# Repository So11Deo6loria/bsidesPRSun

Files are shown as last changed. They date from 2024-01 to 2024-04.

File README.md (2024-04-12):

badgePromo

# BSidesPR Taino Sun
Welcome to BSides Puerto Rico 2024!!! We were happy to have the opportunity to create this year's badge! 

# Functionality
The badge has a default color pattern but we made it highly configurable on purpose. We would love to see all the custom color schemes that people come up with! Come see us to learn more about how you can modify the badge! 

# Troubleshooting
Come find one of the makers on the back of the badge if you have any issues. We will be speaking in the Main Hall (104 B & C) from 1405-1435 on Friday and conducting workshops in 102B on Saturday from 1010-1125. 

Please note that if the badge is running consistently, the battery life will be limited.

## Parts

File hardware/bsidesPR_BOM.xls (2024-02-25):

PCBWay Bom Quotation, Product No.:T-Z9W584267A
Item # | *Designator | *Qty | Manufacturer | *Mfg Part # | Description / Value | *Package/Footprint | Mounting Type | Your Instructions / Notes | Unit Price | *Total | *Delivery Time | *Actual Purchase Mfg Part # | *PCBWay Note | Customer Reply | PCBWay Update
1 | BT1 | 1 |  | 2464 | Keystone 2464 | 2464 | Through Hole
2 | C1, C2, C4, C5 | 4 | Taiyo Yuden | JMK212BJ475MG-T | 4.7uF | Capacitor_SMD:C_0805_2012Metric_Pad1.18x1.45mm_HandSolder | Surface Mount, MLCC |  |  | $0.000
3 | C3 | 1 | Vishay Vitramon | VJ0603A3R3BXJCW1BC | 3.3pF | Capacitor_SMD:C_0603_1608Metric_Pad1.08x0.95mm_HandSolder | Surface Mount, MLCC |  |  | $0.000
4 | D1, D2, D3, D4, D5, D6, D7, D8, D9, D10, D11, D12, D13, D14, D15, D16, D17, D18, D19, D20, D21, D22, D23, D24, D25, D26, D27, D28, D29, D30, D31, D32, D33, D34, D35, D36, D37, D38, D39, D40, D41, D42, D43, D44, D45, D46, D47, D48, D49, D50 | 50 | worldsemi | SK6812 | WS2812B-B/W | LED_SMD:LED_WS2812B_PLCC4_5.0x5.0mm_P3.2mm |  |  |  | $0.000
5 | D51, D52 | 2 | onsemi |  | MBR0530T3G | Diode_SMD:D_SOD-123 | Surface Mount |  |  | $0.000
7 | J3 | 1 |  |  | Conn_01x03_Female | Connector_PinHeader_2.54mm:PinHeader_1x03_P2.54mm_Vertical |  | DNP: X
8 | L1 | 1 | TDK Corporation | MLP2520S3R3MT0S1 | 3.3uH | Inductor_SMD:L_1008_2520Metric_Pad1.43x2.20mm_HandSolder | Surface Mount |  |  | $0.000
9 | Q1 | 1 | Diodes Incorporated |  | 2N7002H | Package_TO_SOT_SMD:SOT-23 | Surface Mount |  |  | $0.000 |  | 2N7002H-7
10 | Q2 | 1 | Diodes Incorporated |  | DMP2012SN-7 | Package_TO_SOT_SMD:SOT-23 | Surface Mount
11 | R1, R4, R5 | 3 | YAGEO | RC0603FR-1310KL | 10k | Resistor_SMD:R_0603_1608Metric_Pad0.98x0.95mm_HandSolder | Surface Mount |  |  | $0.000
12 | R2 | 1 | YAGEO | RT0603FRE07620KL | 620k | Resistor_SMD:R_0603_1608Metric_Pad0.98x0.95mm_HandSolder | Surface Mount |  |  | $0.000
13 | R3 | 1 | YAGEO | RT0603FRE07200KL | 200k | Resistor_SMD:R_0603_1608Metric_Pad0.98x0.95mm_HandSolder | Surface Mount |  |  | $0.000
14 | R6 | 4 | YAGEO | RC0603FR-07499RL | 500 | Resistor_SMD:R_0603_1608Metric_Pad0.98x0.95mm_HandSolder | Surface Mount |  |  | $0.000
15 | SW1 | 1 | SHOU HAN | TS5225A | SW_MEC_5G | Button_Switch_SMD:SW_SPST_EVPBF | Surface Mount |  |  | $0.000
16 | U1 | 1 | raspberry pi | https://www.newark.com/raspberry-pi/raspberry-pi-pico/raspberry-pi-board-arm-cortex/dp/22AJ1097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 | Pico | MCU_RaspberryPi_and_Boards:RPi_Pico_SMD_TH | Surface Mount |  |  |  |  | 22AJ1097
17 | U2 | 1 | Texas Instruments | TPS61040DDCT | TPS61040DDC | Package_TO_SOT_SMD:SOT-23-5 | Surface Mount

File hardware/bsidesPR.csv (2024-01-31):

 |  |  |  |  |  |  | We have previously purchased a similar board and here are some details of that purchase.
# | Reference | Qty | Value | Footprint | Estimated Price (Per Board) | DNP | Actual Purchase Mfg Part # | Unit Price
1 | BT2 | 1 | 2477 | 2477:BAT_2477 | FALSE | X
2 | C1, C2, C4, C5 | 4 | 4.7uF | Capacitor_SMD:C_0805_2012Metric_Pad1.18x1.45mm_HandSolder | $0.384 |  | JMK212BJ475MG-T | $0.096
3 | C3 | 1 | 3.3pF | Capacitor_SMD:C_0603_1608Metric_Pad1.08x0.95mm_HandSolder | $0.104 |  | VJ0603A3R3BXJCW1BC | $0.104
4 | D1, D2, D3, D4, D5, D6, D7, D8, D9, D10, D11, D12, D13, D14, D15, D16, D17, D18, D19, D20, D21, D22, D23, D24, D25, D26, D27, D28, D29, D30, D31, D32, D33, D34, D35, D36, D37, D38, D39, D40, D41, D42, D43, D44, D45, D46, D47, D48, D49, D50 | 50 | WS2812B | LED_SMD:LED_WS2812B_PLCC4_5.0x5.0mm_P3.2mm | $2.250 |  | SK6812 | $0.045
5 | D51, D52 | 2 | BAT54W-HG3-18 | Diode_SMD:D_SOD-123 | $0.326 |  |  | $0.163
6 | J1 | 1 | Conn_02x03_Odd_Even | Connector_PinHeader_2.54mm:PinHeader_2x03_P2.54mm_Vertical | FALSE | X
7 | J3 | 1 | Conn_01x03_Female | Connector_PinHeader_2.54mm:PinHeader_1x03_P2.54mm_Vertical | FALSE | X
8 | L1 | 1 | 3.3uH | Inductor_SMD:L_1008_2520Metric_Pad1.43x2.20mm_HandSolder | $0.089 |  | MLP2520S3R3MT0S1 | $0.089
9 | Q1 | 1 | 2N7002H | Package_TO_SOT_SMD:SOT-23 | $0.299 |  |  | $0.299
10 | Q2 | 1 | DMP2012SN-7 | Package_TO_SOT_SMD:SOT-23 | $0.158 |  |  | $0.158
11 | R1, R4, R5 | 3 | 10k | Resistor_SMD:R_0603_1608Metric_Pad0.98x0.95mm_HandSolder | $0.003 |  | RC0603FR-1310KL | $0.001
12 | R2 | 1 | 620k | Resistor_SMD:R_0603_1608Metric_Pad0.98x0.95mm_HandSolder | $0.016 |  | RT0603FRE07620KL | $0.016
13 | R3 | 1 | 200k | Resistor_SMD:R_0603_1608Metric_Pad0.98x0.95mm_HandSolder | $0.015 |  | RT0603FRE07200KL | $0.015
14 | R6, R7, R8, R9 | 4 | 500 | Resistor_SMD:R_0603_1608Metric_Pad0.98x0.95mm_HandSolder | $0.008 |  | RC0603FR-07499RL | $0.002
15 | SW1 | 1 | SW_MEC_5G | Button_Switch_SMD:SW_SPST_EVPBF | $0.027 |  | TS5225A | $0.027
16 | U1 | 1 | Pico | MCU_RaspberryPi_and_Boards:RPi_Pico_SMD_TH | $5.000 |  | https://www.newark.com/raspberry-pi/raspberry-pi-pico/raspberry-pi-board-arm-cortex/dp/22AJ1097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 | $5.000
17 | U2 | 1 | TPS61040DDC | Package_TO_SOT_SMD:SOT-23-5 | $0.494 |  | TPS61040DDCT | $0.494
 |  |  |  | Estimated BoM | $9.173
 |  |  |  | Total Boards | 300
 |  |  |  | Estimated Material Cost | $2,751.90

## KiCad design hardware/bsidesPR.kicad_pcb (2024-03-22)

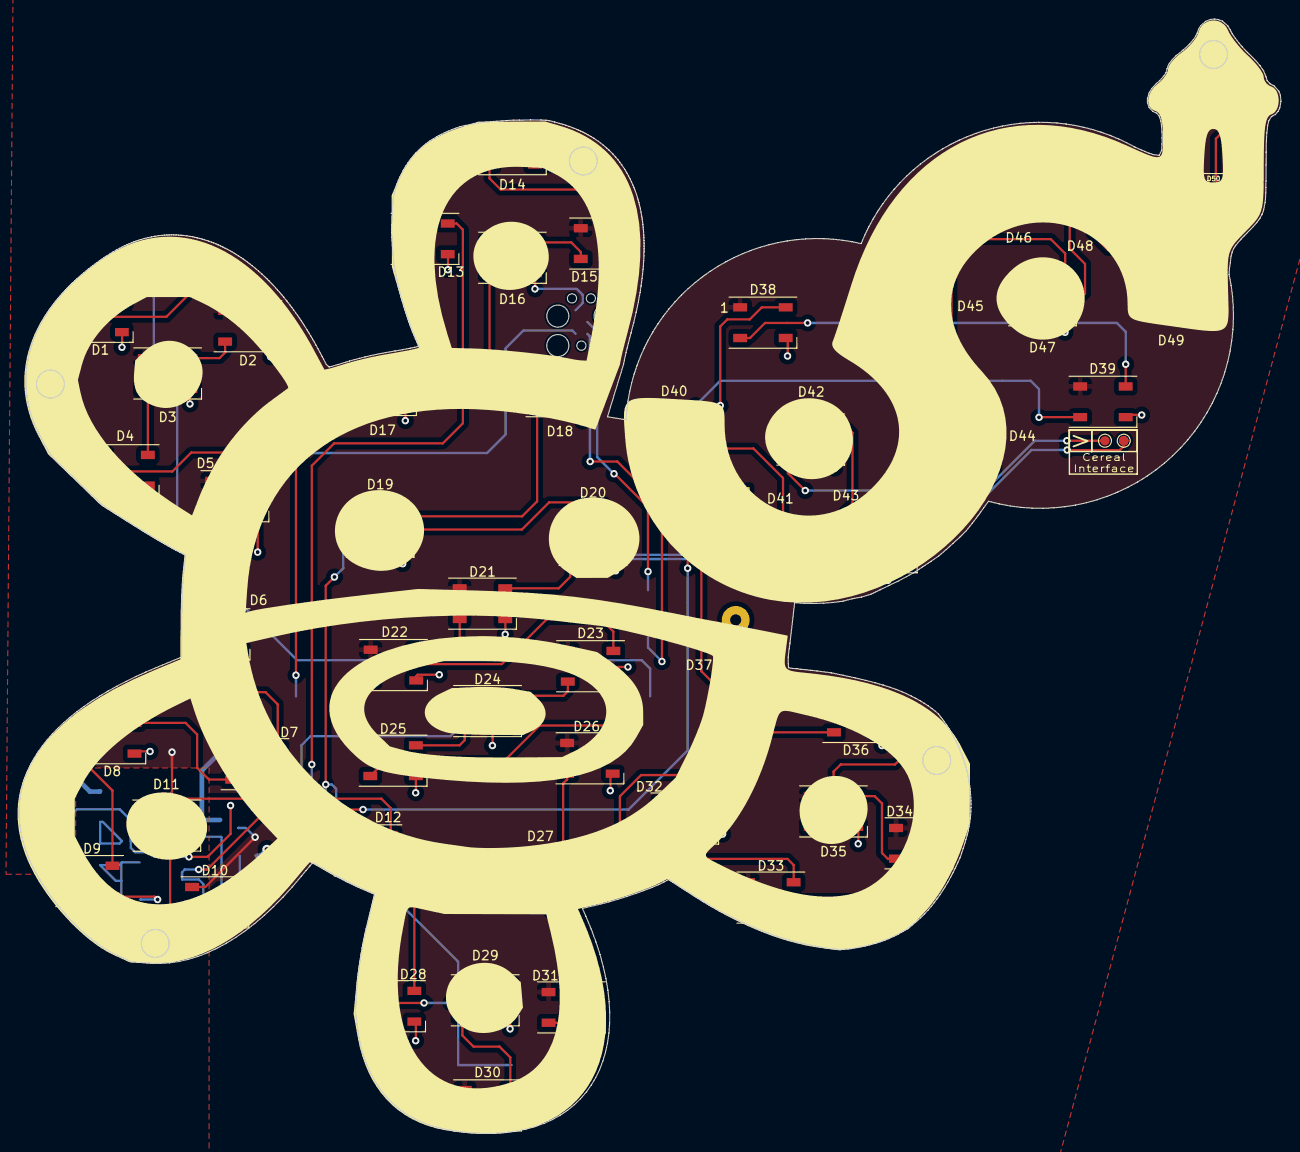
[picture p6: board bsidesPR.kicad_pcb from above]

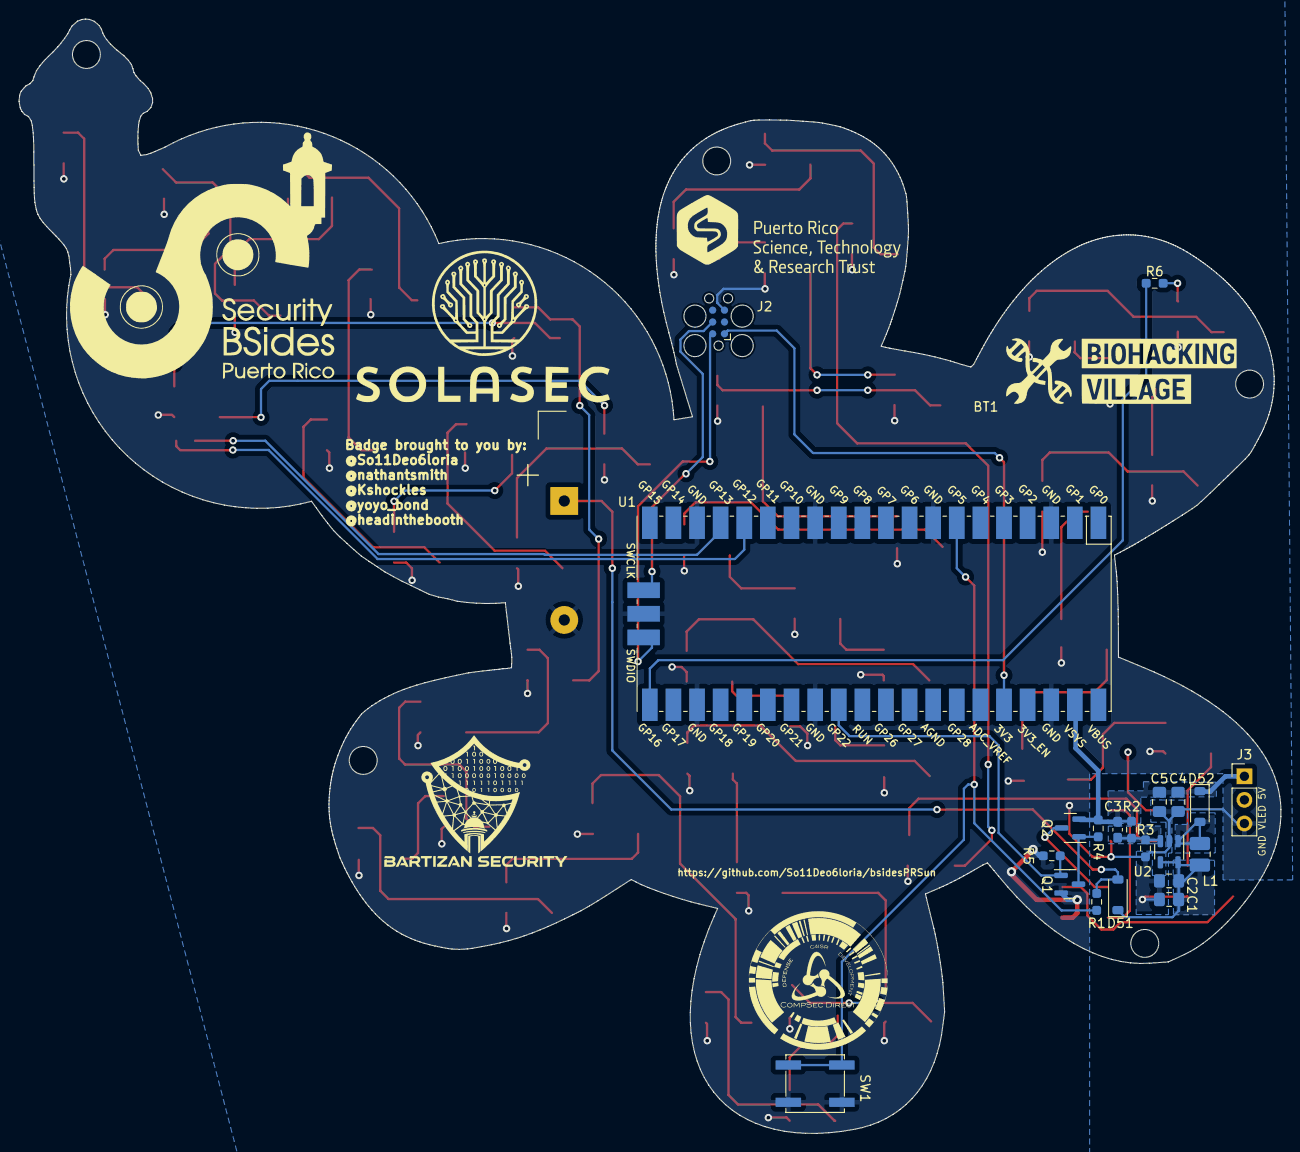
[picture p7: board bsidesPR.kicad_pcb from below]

Board: 2 copper layers, 135.8 x 119.9 mm, 72 parts (22 on the bottom side), 64 nets.

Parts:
BT1: Battery; BatteryHolder_TruPower_BH-331P_3xAA
C1, C2, C4, C5: 4.7uF; C_0805_2012Metric_Pad1.18x1.45mm_HandSolder
C3: 3.3pF; C_0603_1608Metric_Pad1.08x0.95mm_HandSolder
D1, D2, D3, D4, D5, D6, D7, D8, D9, D10, D11, D12, D13, D14, D15, D16, D17, D18, D19, D20, D21, D22, D23, D24, D25, D26, D27, D28, D29, D30, D31, D32, D33, D34, D35, D36, D37, D38, D39, D40, D41, D42, D43, D44, D45, D46, D47, D48, D49, D50: WS2812B; LED_WS2812B_PLCC4_5.0x5.0mm_P3.2mm
D51, D52: BAT54W-HG3-18; D_SOD-123
J2: Conn_ARM_SWD_TagConnect_TC2030; Tag-Connect_TC2030-IDC-FP_2x03_P1.27mm_Vertical
J3: Conn_01x03_Female; PinHeader_1x03_P2.54mm_Vertical
L1: 3.3uH; L_1008_2520Metric_Pad1.43x2.20mm_HandSolder
Q1: 2N7002H; SOT-23
Q2: DMP2012SN-7; SOT-23
R1, R4, R5: 10k; R_0603_1608Metric_Pad0.98x0.95mm_HandSolder
R2: 620k; R_0603_1608Metric_Pad0.98x0.95mm_HandSolder
R3: 200k; R_0603_1608Metric_Pad0.98x0.95mm_HandSolder
R6: 500; R_0603_1608Metric_Pad0.98x0.95mm_HandSolder
SW1: SW_MEC_5G; SW_SPST_EVPBF
U1: Pico; RPi_Pico_SMD_TH
U2: TPS61040DDC; SOT-23-5

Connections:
+3V3: J2.1 (VCC), U1.36 (3V3)
+5V: C3.1, C4.1, C5.1, D52.1 (K), J3.1, Q2.2 (S), R2.1, R4.1, U1.39 (VSYS)
/EN: C1.1, C2.1, D51.1 (K), L1.1, U2.4 (EN), U2.5 (VIN)
/FB: C3.2, R2.2, R3.1, U2.3 (FB)
/SW: D52.2 (A), L1.2, U2.1 (SW)
ENABLE_VLED: Q1.1 (G), R5.1, U1.29 (GPIO22)
GND: BT1.2 (-), C1.2, C2.2, C4.2, C5.2, D1.3 (VSS), D2.3 (VSS), D3.3 (VSS), D4.3 (VSS), D5.3 (VSS), D6.3 (VSS), D7.3 (VSS), D8.3 (VSS), D9.3 (VSS), D10.3 (VSS), D11.3 (VSS), D12.3 (VSS), D13.3 (VSS), D14.3 (VSS), D15.3 (VSS), D16.3 (VSS), D17.3 (VSS), D18.3 (VSS), D19.3 (VSS), D20.3 (VSS), D21.3 (VSS), D22.3 (VSS), D23.3 (VSS), D24.3 (VSS), D25.3 (VSS), D26.3 (VSS), D27.3 (VSS), D28.3 (VSS), D29.3 (VSS), D30.3 (VSS), D31.3 (VSS), D32.3 (VSS), D33.3 (VSS), D34.3 (VSS), D35.3 (VSS), D36.3 (VSS), D37.3 (VSS), D38.3 (VSS), D39.3 (VSS), D40.3 (VSS), D41.3 (VSS), D42.3 (VSS), D43.3 (VSS), D44.3 (VSS), D45.3 (VSS), D46.3 (VSS), D47.3 (VSS), D48.3 (VSS), D49.3 (VSS), D50.3 (VSS), J2.5 (GND), J3.3, Q1.2 (S), R3.2, R5.2, SW1.2 (B), SW1.4 (B), U1.3 (GND), U1.8 (GND), U1.13 (GND), U1.18 (GND), U1.23 (GND), U1.28 (GND), U1.38 (GND), U1.42 (GND), U2.2 (GND)
LED_PIN: R6.1, U1.21 (GPIO16)
unnamed: BT1.1 (+), D51.2 (A), R1.1
unnamed: D1.4 (DIN), R6.2
unnamed: D1.2 (DOUT), D2.4 (DIN)
unnamed: D2.2 (DOUT), D3.4 (DIN)
unnamed: D3.2 (DOUT), D4.4 (DIN)
unnamed: D4.2 (DOUT), D5.4 (DIN)
unnamed: D5.2 (DOUT), D6.4 (DIN)
unnamed: D6.2 (DOUT), D7.4 (DIN)
unnamed: D7.2 (DOUT), D8.4 (DIN)
unnamed: D8.2 (DOUT), D9.4 (DIN)
unnamed: D9.2 (DOUT), D10.4 (DIN)
unnamed: D10.2 (DOUT), D11.4 (DIN)
unnamed: D11.2 (DOUT), D12.4 (DIN)
unnamed: D12.2 (DOUT), D13.4 (DIN)
unnamed: D13.2 (DOUT), D14.4 (DIN)
unnamed: D14.2 (DOUT), D15.4 (DIN)
unnamed: D15.2 (DOUT), D16.4 (DIN)
unnamed: D16.2 (DOUT), D17.4 (DIN)
unnamed: D17.2 (DOUT), D18.4 (DIN)
unnamed: D18.2 (DOUT), D19.4 (DIN)
unnamed: D19.2 (DOUT), D20.4 (DIN)
unnamed: D20.2 (DOUT), D21.4 (DIN)
unnamed: D21.2 (DOUT), D22.4 (DIN)
unnamed: D22.2 (DOUT), D23.4 (DIN)
unnamed: D23.2 (DOUT), D24.4 (DIN)
unnamed: D24.2 (DOUT), D25.4 (DIN)
unnamed: D25.2 (DOUT), D26.4 (DIN)
unnamed: D26.2 (DOUT), D27.4 (DIN)
unnamed: D27.2 (DOUT), D28.4 (DIN)
unnamed: D28.2 (DOUT), D29.4 (DIN)
unnamed: D29.2 (DOUT), D30.4 (DIN)
unnamed: D30.2 (DOUT), D31.4 (DIN)
unnamed: D31.2 (DOUT), D32.4 (DIN)
unnamed: D32.2 (DOUT), D33.4 (DIN)
unnamed: D33.2 (DOUT), D34.4 (DIN)
unnamed: D34.2 (DOUT), D35.4 (DIN)
unnamed: D35.2 (DOUT), D36.4 (DIN)
unnamed: D36.2 (DOUT), D37.4 (DIN)
unnamed: D37.2 (DOUT), D38.4 (DIN)
unnamed: D38.2 (DOUT), D39.4 (DIN)
unnamed: D39.2 (DOUT), D40.4 (DIN)
unnamed: D40.2 (DOUT), D41.4 (DIN)
unnamed: D41.2 (DOUT), D42.4 (DIN)
unnamed: D42.2 (DOUT), D43.4 (DIN)
unnamed: D43.2 (DOUT), D44.4 (DIN)
unnamed: D44.2 (DOUT), D45.4 (DIN)
unnamed: D45.2 (DOUT), D46.4 (DIN)
unnamed: D46.2 (DOUT), D47.4 (DIN)
unnamed: D47.2 (DOUT), D48.4 (DIN)
unnamed: D48.2 (DOUT), D49.4 (DIN)
unnamed: D49.2 (DOUT), D50.4 (DIN)
unnamed: J2.4 (SWCLK), U1.41 (SWCLK)
unnamed: J2.2 (SWDIO), U1.43 (SWDIO)
unnamed: Q1.3 (D), Q2.1 (G), R4.2
RPi_WAKE: R1.2, SW1.1 (A), U1.7 (GPIO5)
VLED: D1.1 (VDD), D2.1 (VDD), D3.1 (VDD), D4.1 (VDD), D5.1 (VDD), D6.1 (VDD), D7.1 (VDD), D8.1 (VDD), D9.1 (VDD), D10.1 (VDD), D11.1 (VDD), D12.1 (VDD), D13.1 (VDD), D14.1 (VDD), D15.1 (VDD), D16.1 (VDD), D17.1 (VDD), D18.1 (VDD), D19.1 (VDD), D20.1 (VDD), D21.1 (VDD), D22.1 (VDD), D23.1 (VDD), D24.1 (VDD), D25.1 (VDD), D26.1 (VDD), D27.1 (VDD), D28.1 (VDD), D29.1 (VDD), D30.1 (VDD), D31.1 (VDD), D32.1 (VDD), D33.1 (VDD), D34.1 (VDD), D35.1 (VDD), D36.1 (VDD), D37.1 (VDD), D38.1 (VDD), D39.1 (VDD), D40.1 (VDD), D41.1 (VDD), D42.1 (VDD), D43.1 (VDD), D44.1 (VDD), D45.1 (VDD), D46.1 (VDD), D47.1 (VDD), D48.1 (VDD), D49.1 (VDD), D50.1 (VDD), J3.2, Q2.3 (D)

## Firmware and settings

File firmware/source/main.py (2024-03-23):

import lowpower
import utime
import time # Remove later
import machine
import _thread
import constants
import prettyLights
import cerealInterface
import ujson
from machine import Pin, Timer

class Main:
    def __init__(self):
        print("Start Up") # only print after receiving signal on Pin number DORMANT_PIN
        self.runLoop()

    def lowPowerPause(self):
        self.leds.shutdown()
        while(self.button.value() != 1):
            utime.sleep_ms(10)
        lowpower.dormant_until_pin(constants.BUTTON)
        self.leds.wakeup()

    def read_config(self):
        try:
            with open('config.json', 'r') as f:
                data = ujson.load(f)
                return data
        except:
            return False
        
    def runLoop(self):
        config = self.read_config()
        if(config):
            print("Loading following configuration:")
            print(config)
            self.startupColorName = config['startupColor']
            self.flagName = config['flag']
            self.sleepTimeout = config['sleepTimeout']
        else:
            print("Loading default configuration")
            self.startupColorName = 'white',
            self.flagName = 'puertoRicoFlag'
            self.sleepTimeout = 300 # 300 seconds
        self.button = Pin(constants.BUTTON, Pin.IN, Pin.PULL_UP)

        #Initialize LED Manager and Turn on Power
        self.leds = prettyLights.LEDS(self.flagName, self.startupColorName)
        self.leds.wakeup()
        self.leds.startupAnimation()

        serialInterface = cerealInterface.CerealInterface(self.leds)
        _thread.start_new_thread(serialInterface.uartShell, ())        

        #Capture the Bootup Time
        startTime = utime.ticks_ms()

        while(True):
            if((self.button.value() != 1) or (utime.ticks_diff(utime.ticks_ms(), startTime) > self.sleepTimeout*1000)):
                print("getting sleepy")
                self.lowPowerPause()
                startTime = utime.ticks_ms()
                self.leds.startupAnimation()
            self.leds.waveDaFlag()
            time.sleep(0.025)

Main()

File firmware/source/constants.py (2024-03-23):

# Board Configuration
BUTTON = 5
PICO_LED_PIN = 25

# LED Constants
LED_OFF = tuple([0, 0, 0])
LED_MAX = 0.200
WAVE_DELAY = 0.1
LED_COUNT = 50

# Serial/UART constants
CEREAL_TX_PIN = 12  # GPIO 12 Pin 16
CEREAL_RX_PIN = 13  # GPIO 13 Pin 17
BAUD_RATE = 115200

COLOR_MAPPING = {
    "white": [255, 255, 255],
    "red": [255, 0, 0],
    "green": [0, 255, 0],
    "blue": [0, 0, 255],
    "yellow": [255, 255, 0],
    "cyan": [0, 255, 255],
    "magenta": [255, 0, 255],
    "orange": [255, 165, 0],
    "purple": [128, 0, 128],
    "lime": [0, 128, 0],
    "teal": [0, 128, 128],
    "navy": [0, 0, 128],
    "maroon": [128, 0, 0],
    "silver": [192, 192, 192]
}

COLOR_SCHEMES = {
    "puertoRicoFlag": [
        "0000ff", "ffffff", "0000ff", "0000ff", "0000ff", "ffffff", "0000ff", "0000ff", "0000ff", "0000ff", 
        "0000ff", "ffffff", "ff0000", "ff0000", "ff0000", "ff0000", "ffffff", "ffffff", "0000ff", "ff0000", 
        "0000ff", "0000ff", "0000ff", "0000ff", "0000ff", "ff0000", "ffffff", "ff0000", "ff0000", "ff0000", 
        "ff0000", "ffffff", "ffffff", "ffffff", "ffffff", "ff0000", "ff0000", "ff0000", "ffffff", "ffffff", 
        "ff0000", "ffffff", "ff0000", "ffffff", "ff0000", "ff0000", "ff0000", "ff0000", "ff0000", "ff0000"     
    ],
    "cinnamonToastCrunch": [
        "b8732d", "d8d09f", "b8732d", "d8d09f", "724705", "724705", "ce9958", "ce9958", "9f633b", "9f633b", 
        "724705", "ce9958", "9f633b", "9f633b", "d8d09f", "d8d09f", "ce9958", "d8d09f", "9f633b", "9f633b", 
        "d8d09f", "724705", "724705", "d8d09f", "d8d09f", "b8732d", "d8d09f", "9f633b", "d8d09f", "b8732d", 
        "9f633b", "b8732d", "9f633b", "ce9958", "b8732d", "d8d09f", "724705", "b8732d", "ce9958", "d8d09f", 
        "724705", "724705", "9f633b", "ce9958", "ce9958", "d8d09f", "9f633b", "724705", "b8732d", "9f633b"     
    ],
    "fruityPebbles": [
        "f0aa37", "00ffd7", "00ffd7", "f0aa37", "00ffd7", "ffd52b", "00ffd7", "f0aa37", "10b990", "2edfb4", 
        "2edfb4", "10b990", "00ffd7", "00ffd7", "00ffd7", "00ffd7", "00ffd7", "ffd52b", "f0aa37", "2edfb4", 
        "00ffd7", "00ffd7", "ffd52b", "00ffd7", "f0aa37", "ffd52b", "ffd52b", "10b990", "2edfb4", "f0aa37", 
        "f0aa37", "00ffd7", "10b990", "2edfb4", "ffd52b", "f0aa37", "10b990", "ffd52b", "10b990", "2edfb4", 
        "2edfb4", "00ffd7", "00ffd7", "ffd52b", "ffd52b", "f0aa37", "f0aa37", "ffd52b", "f0aa37", "10b990"
    ],
    "luckyCharms": [
        "bdd9a3", "216209", "bdd9a3", "56a20d", "8fac06", "91d521", "56a20d", "8fac06", "216209", "91d521",
        "216209", "8fac06", "216209", "56a20d", "8fac06", "8fac06", "bdd9a3", "56a20d", "8fac06", "56a20d", 
        "216209", "bdd9a3", "bdd9a3", "91d521", "91d521", "bdd9a3", "8fac06", "56a20d", "91d521", "216209", 
        "216209", "56a20d", "8fac06", "8fac06", "91d521", "216209", "91d521", "216209", "216209", "8fac06", 
        "bdd9a3", "bdd9a3", "56a20d", "8fac06", "91d521", "56a20d", "bdd9a3", "8fac06", "8fac06", "bdd9a3"     
    ],
    "fruityPebbles": [
        "ff0000", "7cff00", "7cff00", "ff0000", "ffe700", "7cff00", "7cff00", "c900ff", "ff0000", "00dfff", 
        "00dfff", "c900ff", "ffe700", "00dfff", "c900ff", "00dfff", "c900ff", "00dfff", "ffe700", "c900ff", 
        "ff0000", "7cff00", "ff0000", "c900ff", "ffe700", "c900ff", "ffe700", "ffe700", "7cff00", "c900ff", 
        "ff0000", "7cff00", "ff0000", "c900ff", "ffe700", "c900ff", "ffe700", "ffe700", "7cff00", "c900ff"
    ],
    "appleJacks": [
        "e4a95d", "ff6254", "e4a95d", "5caf4c", "e4a95d", "e4a95d", "ffc360", "fff4a3", "5caf4c", "5caf4c", 
        "ff6254", "ff6254", "5caf4c", "ff6254", "e4a95d", "e4a95d", "5caf4c", "e4a95d", "e4a95d", "ffc360", 
        "5caf4c", "5caf4c", "e4a95d", "5caf4c", "ffc360", "ffc360", "ff6254", "ff6254", "ff6254", "ff6254", 
        "e4a95d", "fff4a3", "ff6254", "fff4a3", "fff4a3", "e4a95d", "ff6254", "ff6254", "ffc360", "ff6254", 
        "e4a95d", "ff6254", "5caf4c", "ff6254", "fff4a3", "5caf4c", "ff6254", "fff4a3", "fff4a3", "e4a95d" 
    ],
    "trix": [
        "f14848", "87a2ff", "87a2ff", "af7ffc", "87a2ff", "da4e7d", "58e3ff", "87a2ff", "f14848", "f14848", 
        "58e3ff", "da4e7d", "da4e7d", "f14848", "58e3ff", "58e3ff", "da4e7d", "f14848", "58e3ff", "af7ffc", 
        "f14848", "da4e7d", "af7ffc", "f14848", "da4e7d", "da4e7d", "87a2ff", "da4e7d", "af7ffc", "87a2ff", 
        "da4e7d", "58e3ff", "da4e7d", "f14848", "da4e7d", "58e3ff", "af7ffc", "da4e7d", "f14848", "58e3ff", 
        "af7ffc", "f14848", "f14848", "f14848", "87a2ff", "58e3ff", "da4e7d", "87a2ff", "87a2ff", "58e3ff"
    ],
    "texasFlag": [
        "0000ff", "0000ff", "0000ff", "0000ff", "0000ff", "ffffff", "0000ff", "0000ff", "0000ff", "0000ff", 
        "0000ff", "0000ff", "0000ff", "0000ff", "ffffff", "0000ff", "0000ff", "ffffff", "0000ff", "ffffff", 
        "0000ff", "0000ff", "ff0000", "0000ff", "0000ff", "ff0000", "ff0000", "0000ff", "0000ff", "0000ff",
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

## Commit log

2024-01-31 Initial code and hardware commit
    [bsidesPR-B_Cu.gbr, bsidesPR-B_Mask.gbr, bsidesPR-B_Paste.gbr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]
2024-02-25 Adding some animation support as well as final hardware files
    [bsidesPR-B_Cu.gbr, bsidesPR-B_Mask.gbr, bsidesPR-B_Paste.gbr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]
2024-02-28 Making minor flow modifications
2024-03-22 Firmware is close. We just need to add the flags, test one more time, and add back the lowpower stuff that messes with rshell.
    [bsidesPR.kicad_pcb, leds.kicad_sch]
2024-03-23 Firmware is good minus the low power stuff I will add tomorrow morning. Nate feel free to rewrite it all tonight
2024-03-23 Updated Wave Constants based on physical LED placement.
